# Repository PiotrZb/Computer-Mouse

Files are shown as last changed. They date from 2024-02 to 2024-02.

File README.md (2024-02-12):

# Computer Mouse project 🖱️

## Description 📜

Educational computer mouse project created in KiCad. The project includes an electrical schematic, PCB schematic and Gerber production files.

pcb1

pcb2

## Contributors 🤝

<div style="display: flex;">
    <a href="https://github.com/lukaszkusgithub"> 
       
    </a> 
</div>

## License 📄



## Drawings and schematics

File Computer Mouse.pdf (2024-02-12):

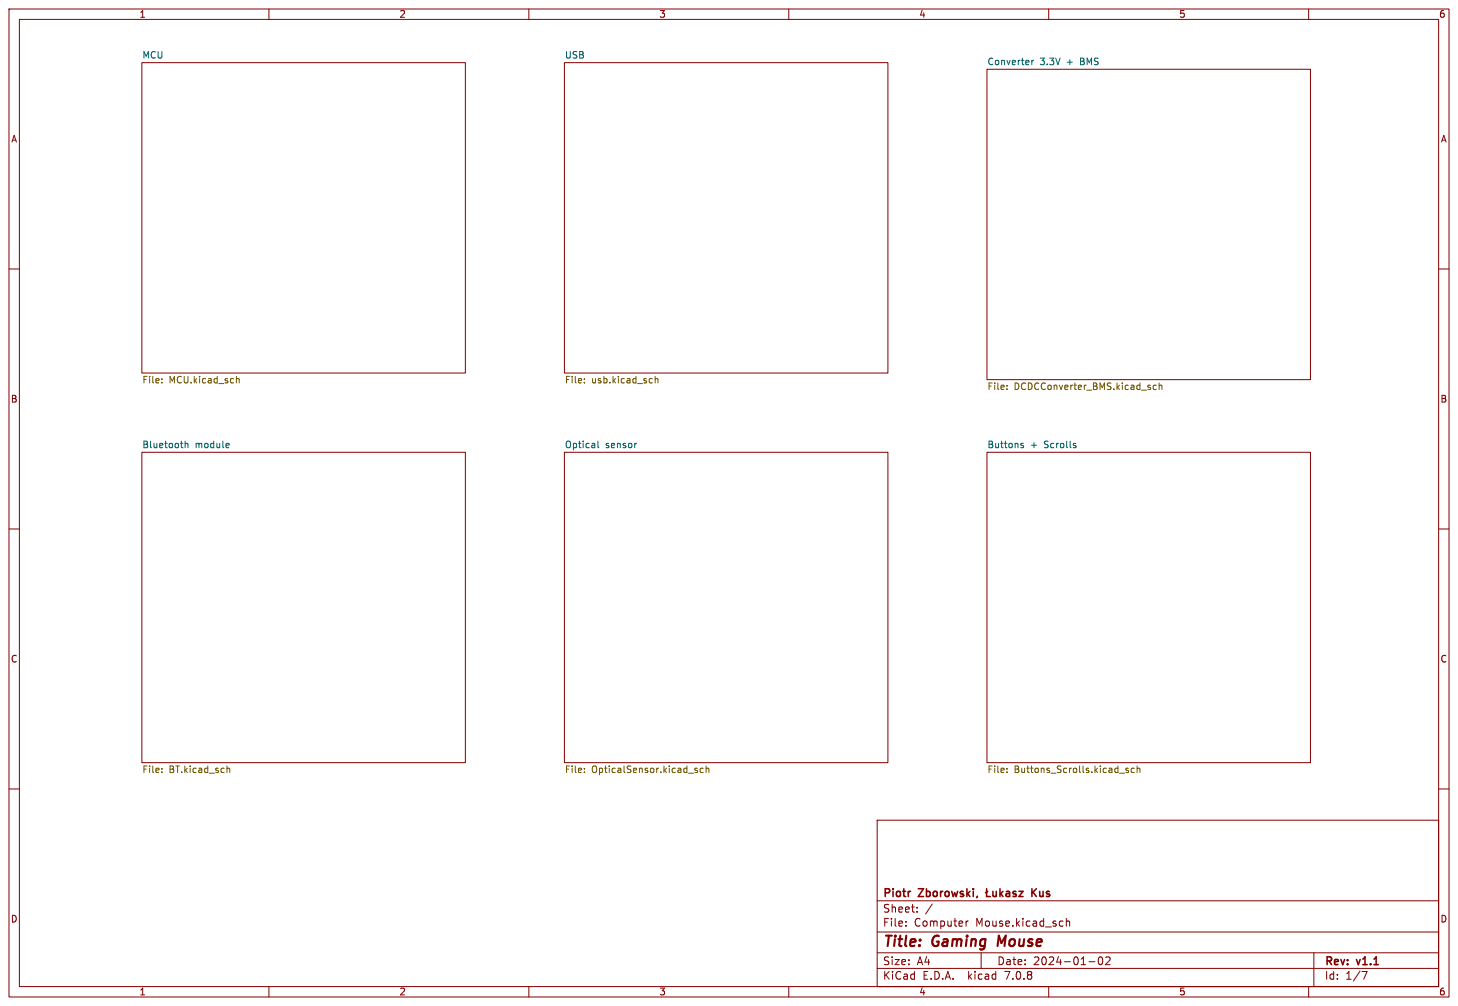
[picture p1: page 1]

File: DCDCConverter_BMS.kicad_sch Optical sensor File: OpticalSensor.kicad_sch

Id: 1/7 Title: Gaming Mouse

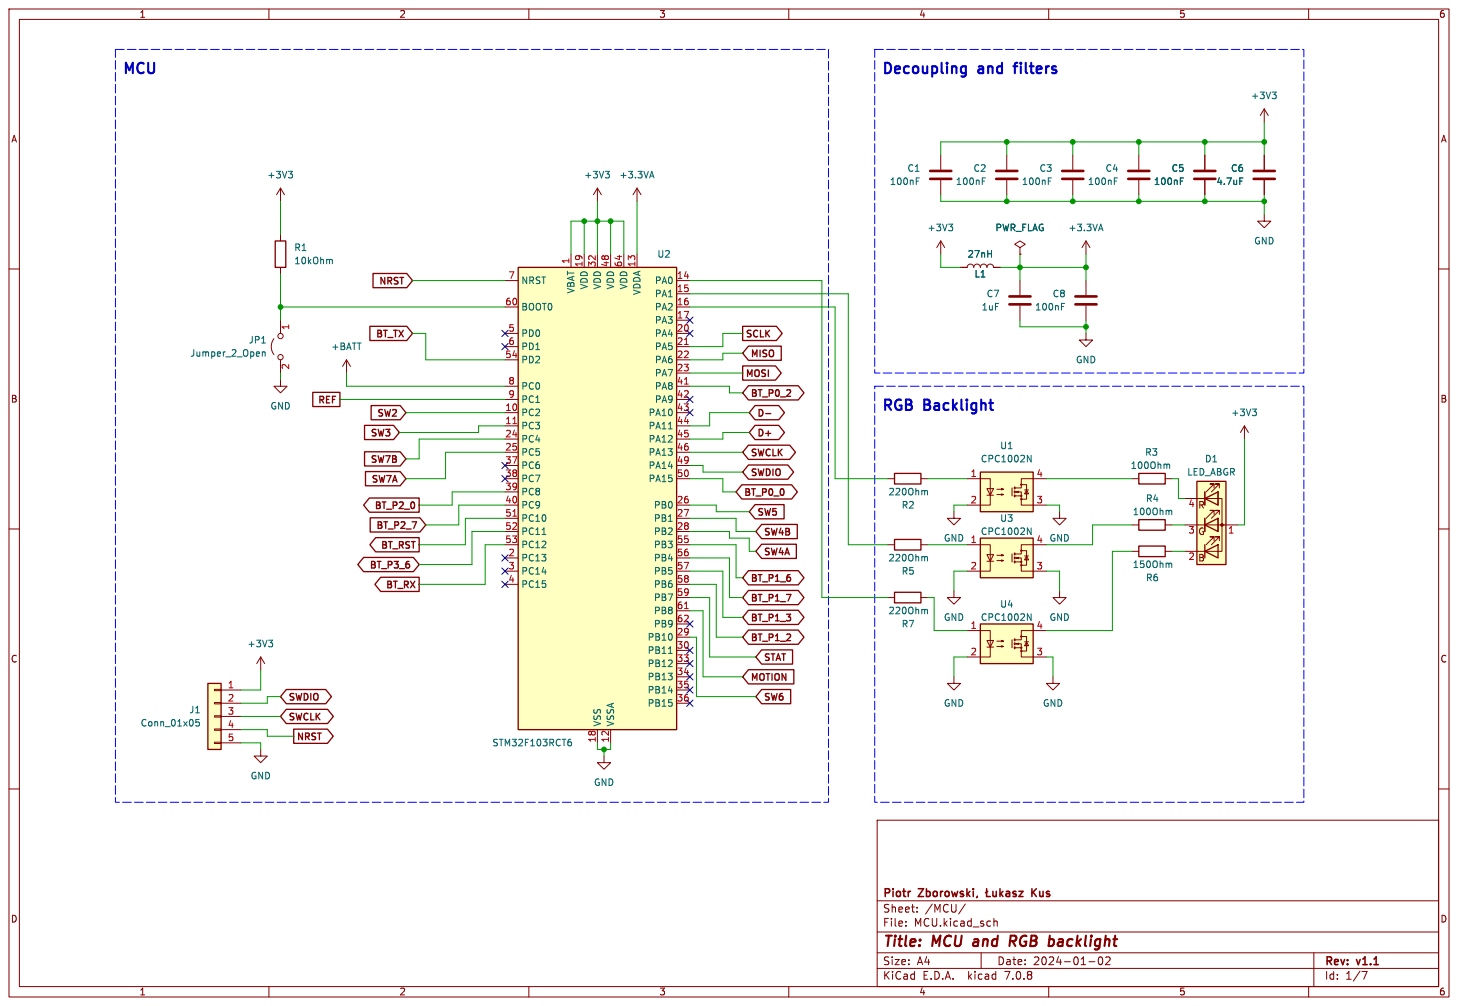
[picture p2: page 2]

1 PC2 10 PC3 11 VSSA 12 VDDA 13 PA0 14 PA1 15 PA2 16 PA3 17 VSS 18 VDD 19 PC13 2 PA4 20 PA5 21 PA6 22 PA7 23 PC4 24 PC5 25 PB0 26 PB1 27 PB2 28 PB10 29 PC14 3 PB11 30 VDD 32 PB12 33 PB13 34 PB14 35 PB15 36 PC6 37 PC7 38 PC8 39 PC15 4 PC9 40 PA8 41 PA9 42 PA10 43 PA11 44 PA12 45 PA13 46 VDD 48 PA14 49 PD0 5 PA15 50 PC10 51 PC11 52 PC12 53 PD2 54 PB3 55 PB4 56 PB5 57 PB6 58 PB7 59 PD1 6 BOOT0 60 PB8 61 PB9 62 VDD 64 NRST 7 PC0 8 PC1 9 U2 STM32F103RCT6

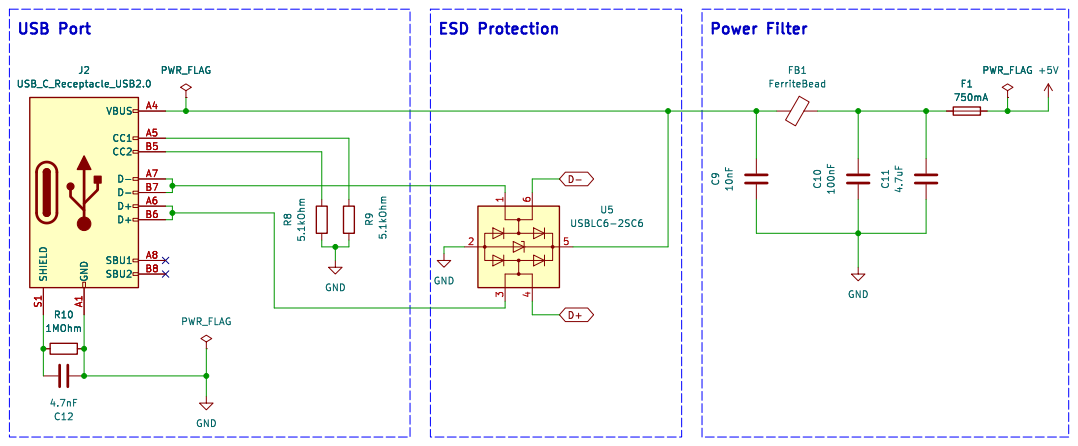
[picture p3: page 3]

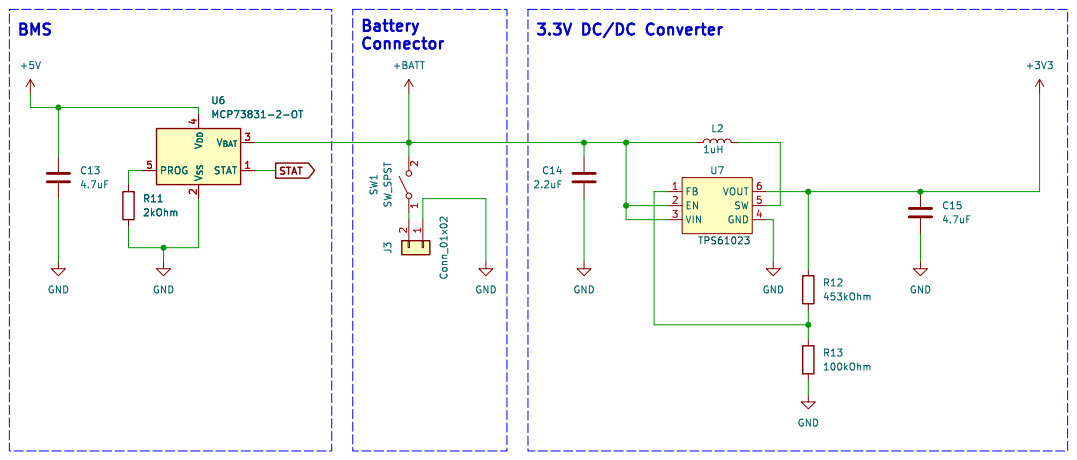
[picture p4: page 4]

1 2 SW1 SW_SPST STAT BMS Battery 3.3V DC/DC Converter

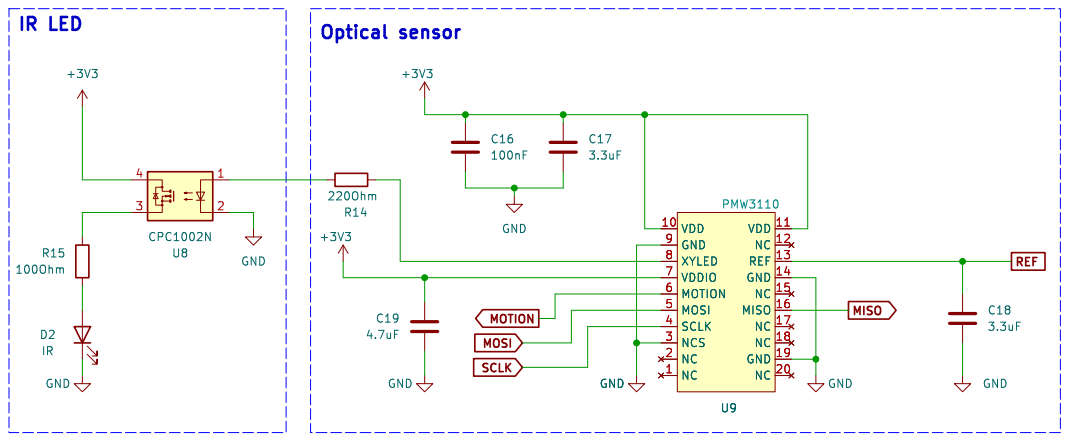
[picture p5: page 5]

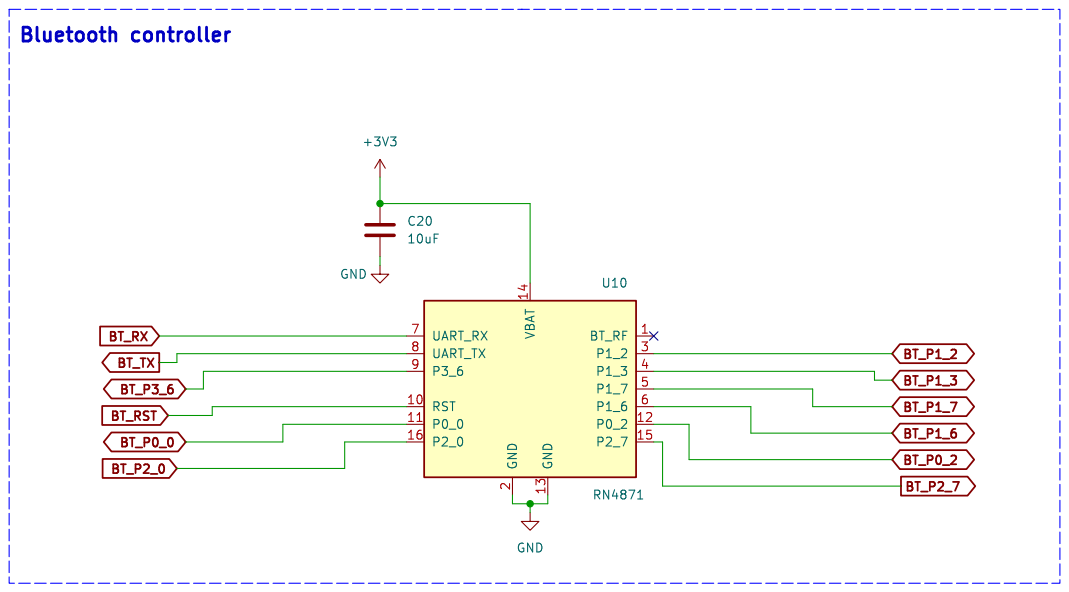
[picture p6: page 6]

Id: 5/7 Title: Bluetooth module

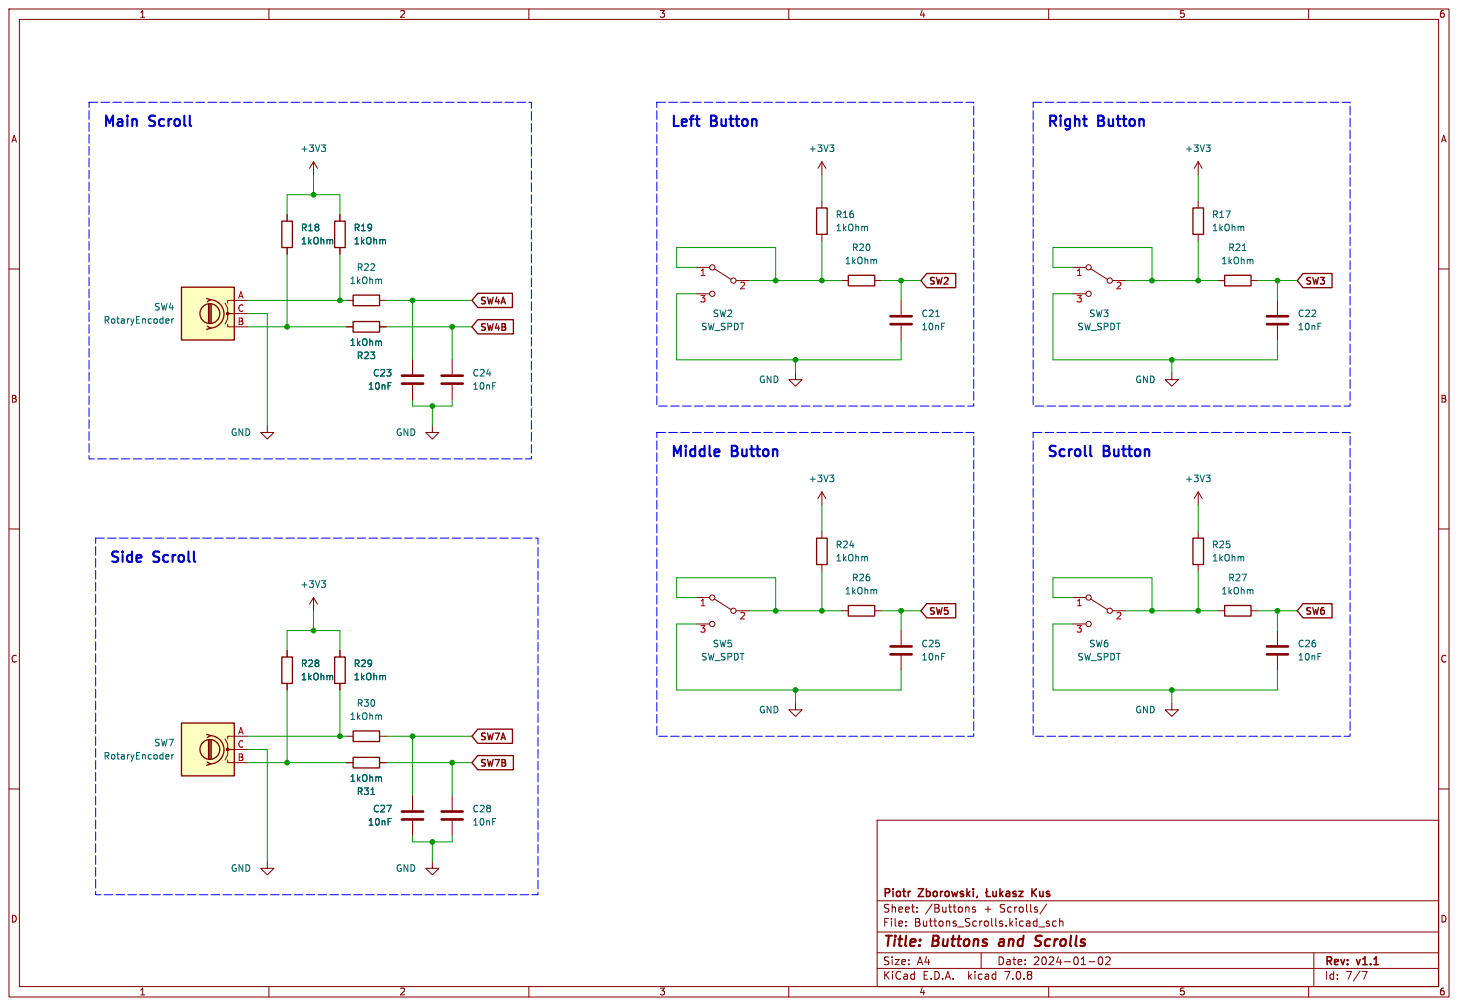
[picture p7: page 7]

Id: 7/7 Title: Buttons and Scrolls

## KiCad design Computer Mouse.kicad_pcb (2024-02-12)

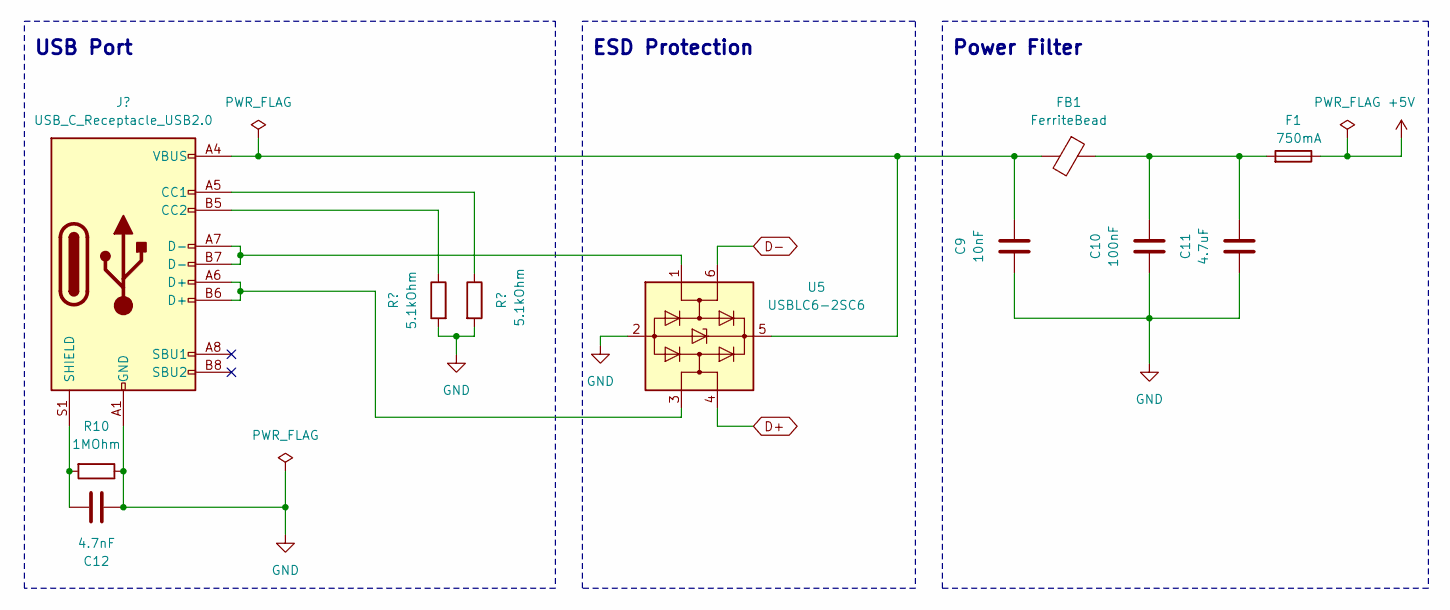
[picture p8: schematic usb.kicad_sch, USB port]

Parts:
C9: 10nF; C_0603_1608Metric
C10: 100nF; C_0805_2012Metric
C11: 4.7uF; C_0603_1608Metric
C12: 4.7nF; C_0805_2012Metric
F1: 750mA; Fuse_0402_1005Metric
FB1: FerriteBead; C_2220_5650Metric
J2: USB_C_Receptacle_USB2.0; USB_C_Receptacle_HRO_TYPE-C-31-M-12
R8, R9: 5.1kOhm; R_0603_1608Metric
R10: 1MOhm; R_1206_3216Metric
U5: USBLC6-2SC6; SOT-23-6

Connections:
+5V: F1.1; also elsewhere on the board
D+: U5.4 (I/O2); also elsewhere on the board
D-: U5.6 (I/O1); also elsewhere on the board
unnamed: C10.2, C11.2, F1.2, FB1.1
unnamed: J2.A5 (CC1), R9.1
unnamed: J2.B5 (CC2), R8.1
unnamed: J2.A6 (D+), J2.B6 (D+), U5.3 (I/O2)
unnamed: J2.A7 (D-), J2.B7 (D-), U5.1 (I/O1)
unnamed: C12.2, J2.S1 (SHIELD), R10.2
unnamed: C9.2, FB1.2, J2.A4 (VBUS), J2.A9 (VBUS), J2.B4 (VBUS), J2.B9 (VBUS), U5.5 (VBUS)

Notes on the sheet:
Power Filter
ESD Protection
USB Port

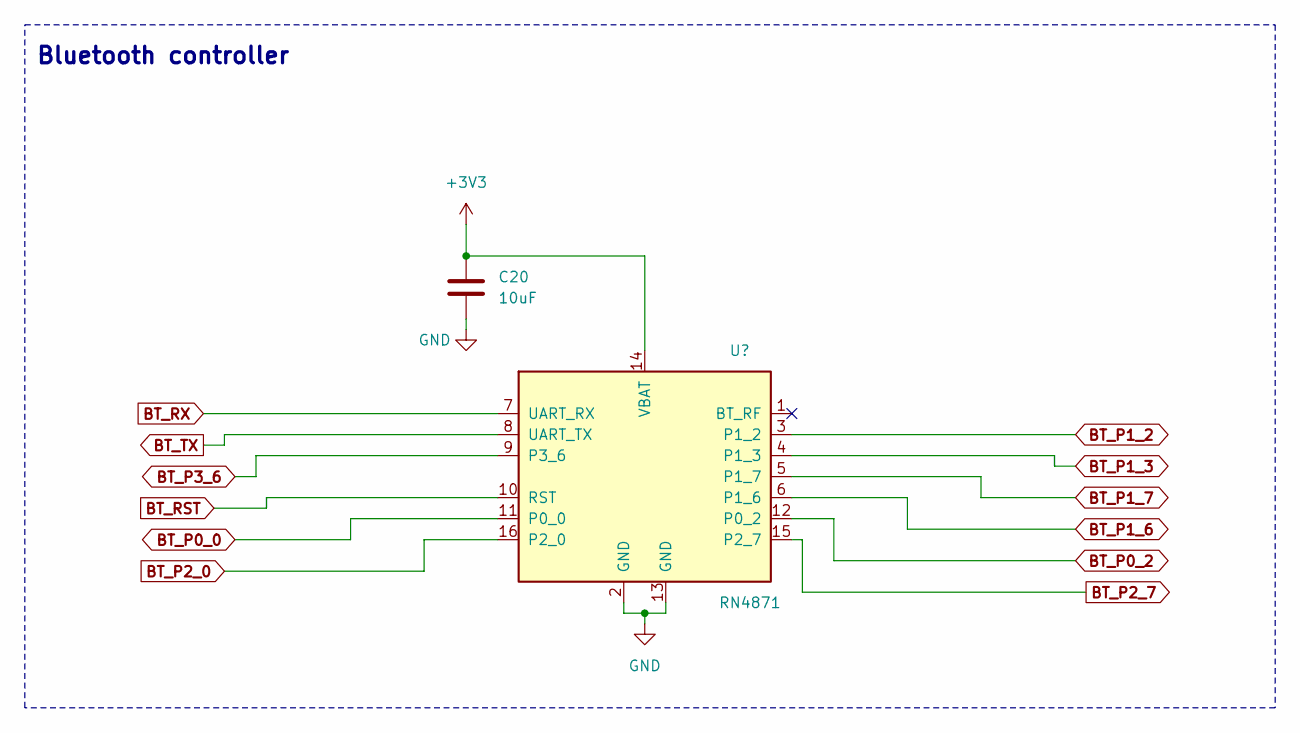
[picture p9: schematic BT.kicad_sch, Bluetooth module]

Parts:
C20: 10uF; C_1206_3216Metric
U10: RN4871; Microchip_RN4871

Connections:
BT_P0_0: U10.11 (P0_0); also elsewhere on the board
BT_P0_2: U10.12 (P0_2); also elsewhere on the board
BT_P1_2: U10.3 (P1_2); also elsewhere on the board
BT_P1_3: U10.4 (P1_3); also elsewhere on the board
BT_P1_6: U10.6 (P1_6); also elsewhere on the board
BT_P1_7: U10.5 (P1_7); also elsewhere on the board
BT_P2_0: U10.16 (P2_0); also elsewhere on the board
BT_P2_7: U10.15 (P2_7); also elsewhere on the board
BT_P3_6: U10.9 (P3_6); also elsewhere on the board
BT_RST: U10.10 (RST); also elsewhere on the board
BT_RX: U10.7 (UART_RX); also elsewhere on the board
BT_TX: U10.8 (UART_TX); also elsewhere on the board

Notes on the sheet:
Bluetooth controller

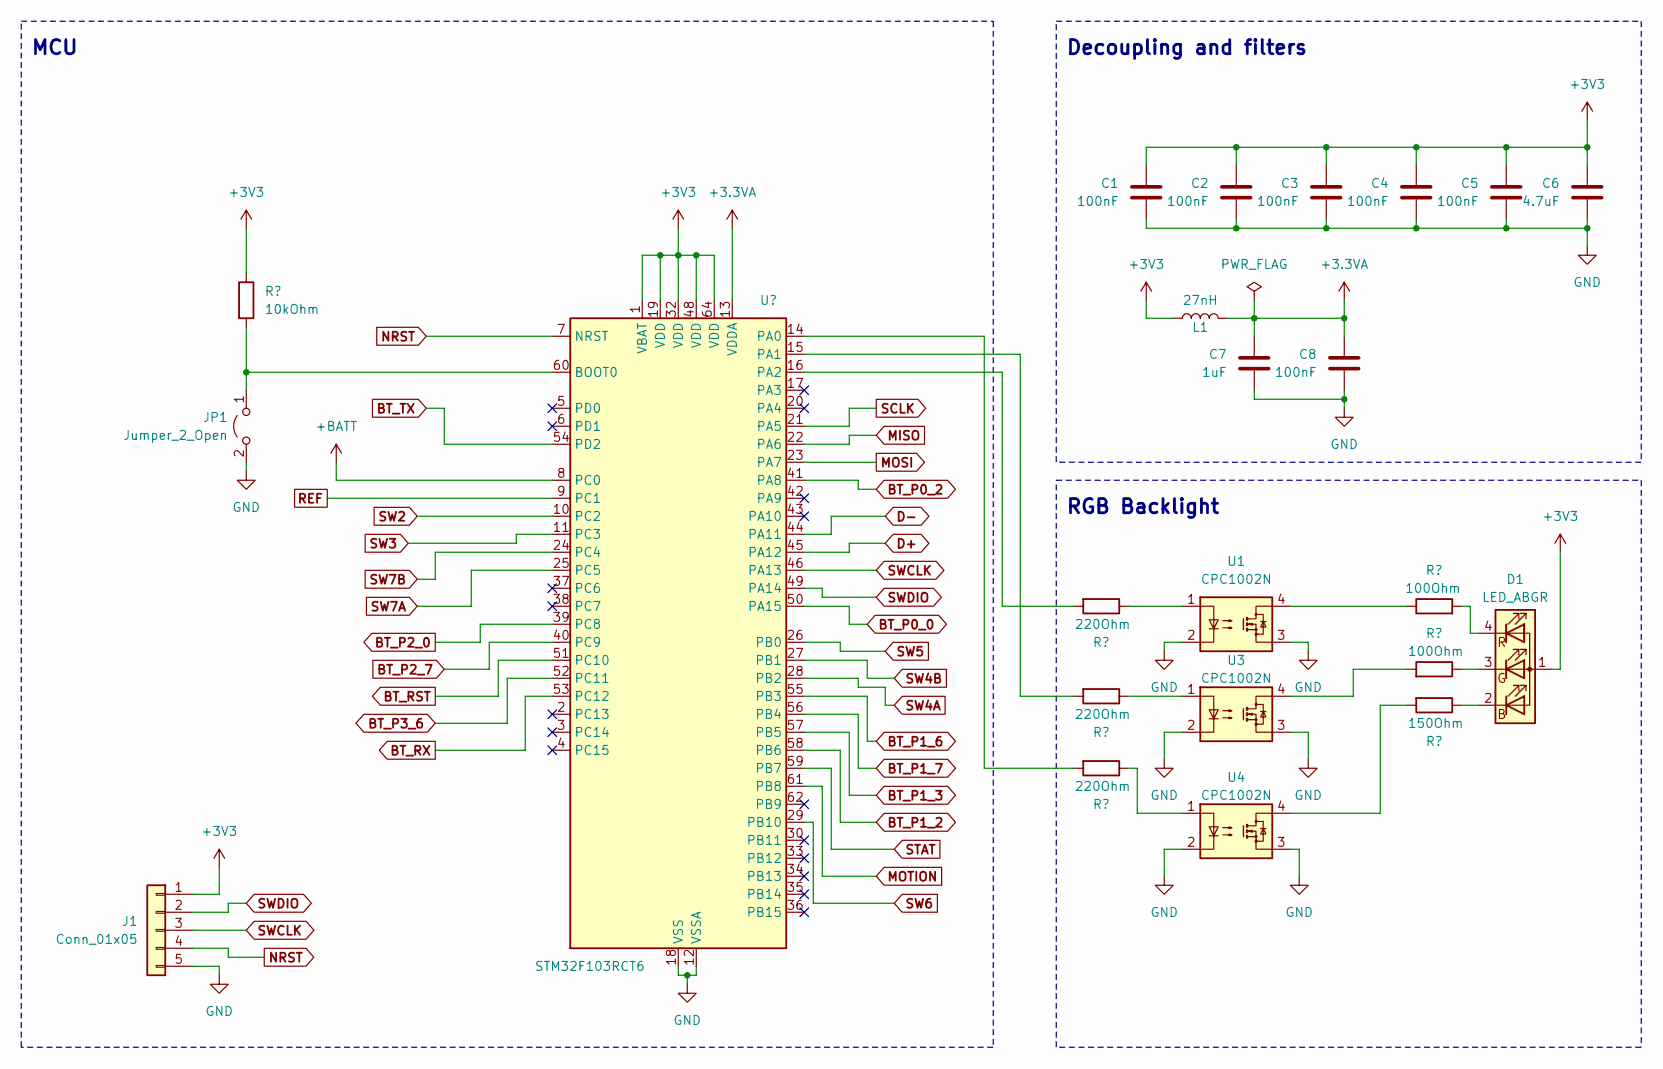
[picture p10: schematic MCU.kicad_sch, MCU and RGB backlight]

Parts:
C1, C2, C3, C4, C5, C8: 100nF; C_0805_2012Metric
C6: 4.7uF; C_0603_1608Metric
C7: 1uF; C_0603_1608Metric
D1: LED_ABGR; LED_D5.0mm-4_RGB_Wide_Pins
J1: Conn_01x05; JST_EH_B5B-EH-A_1x05_P2.50mm_Vertical
JP1: Jumper_2_Open; SolderJumper-2_P1.3mm_Bridged2Bar_Pad1.0x1.5mm
L1: 27nH; L_1210_3225Metric
R1: 10kOhm; R_0805_2012Metric
R2, R5, R7: 220Ohm; R_1206_3216Metric
R3, R4: 100Ohm; R_0805_2012Metric
R6: 150Ohm; R_1206_3216Metric
U1, U3, U4: CPC1002N; SOP-4_3.8x4.1mm_P2.54mm
U2: STM32F103RCT6; LQFP-64_10x10mm_P0.5mm

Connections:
+3.3VA: C7.1, C8.1, L1.1, U2.13 (VDDA)
+BATT: U2.8 (PC0); also elsewhere on the board
BT_P0_0: U2.50 (PA15); also elsewhere on the board
BT_P0_2: U2.41 (PA8); also elsewhere on the board
BT_P1_2: U2.58 (PB6); also elsewhere on the board
BT_P1_3: U2.57 (PB5); also elsewhere on the board
BT_P1_6: U2.55 (PB3); also elsewhere on the board
BT_P1_7: U2.56 (PB4); also elsewhere on the board
BT_P2_0: U2.39 (PC8); also elsewhere on the board
BT_P2_7: U2.40 (PC9); also elsewhere on the board
BT_P3_6: U2.52 (PC11); also elsewhere on the board
BT_RST: U2.51 (PC10); also elsewhere on the board
BT_RX: U2.53 (PC12); also elsewhere on the board
BT_TX: U2.54 (PD2); also elsewhere on the board
D+: U2.45 (PA12); also elsewhere on the board
D-: U2.44 (PA11); also elsewhere on the board
MISO: U2.22 (PA6); also elsewhere on the board
MOSI: U2.23 (PA7); also elsewhere on the board
MOTION: U2.61 (PB8); also elsewhere on the board
NRST: J1.4, U2.7 (NRST)
unnamed: D1.2 (BK), R6.1
unnamed: D1.3 (GK), R4.1
unnamed: D1.4 (RK), R3.2
unnamed: JP1.1 (A), R1.2, U2.60 (BOOT0)
unnamed: R3.1, U1.4
unnamed: R4.2, U3.4
unnamed: R5.1, U3.1
unnamed: R6.2, U4.4
unnamed: R7.1, U4.1
unnamed: R7.2, U2.14 (PA0)
unnamed: R5.2, U2.15 (PA1)
REF: U2.9 (PC1); also elsewhere on the board
STAT: U2.59 (PB7); also elsewhere on the board
SW2: U2.10 (PC2); also elsewhere on the board
SW3: U2.11 (PC3); also elsewhere on the board
SW4A: U2.28 (PB2); also elsewhere on the board
SW4B: U2.27 (PB1); also elsewhere on the board
SW5: U2.26 (PB0); also elsewhere on the board
SW6: U2.29 (PB10); also elsewhere on the board
SW7A: U2.25 (PC5); also elsewhere on the board
SW7B: U2.24 (PC4); also elsewhere on the board
SWCLK: J1.3, U2.46 (PA13)
SWDIO: J1.2, U2.49 (PA14)

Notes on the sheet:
Decoupling and filters
RGB Backlight
MCU

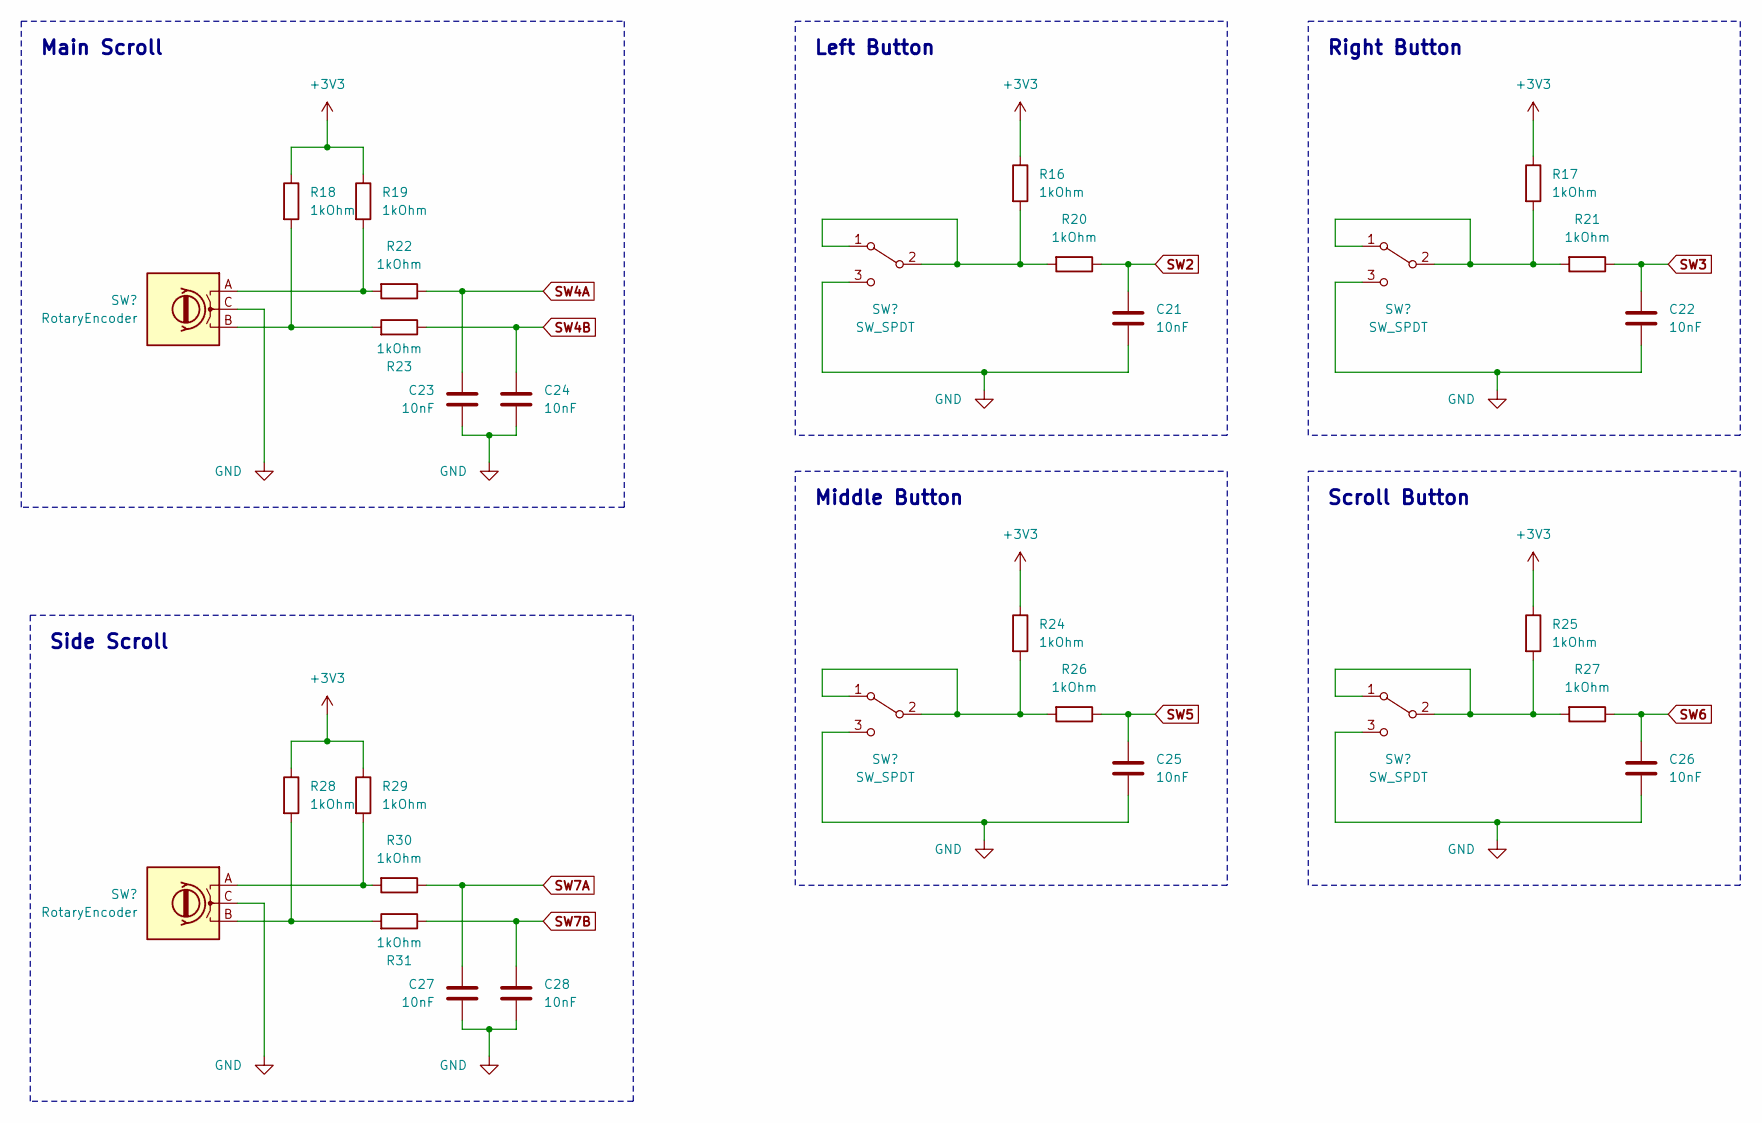
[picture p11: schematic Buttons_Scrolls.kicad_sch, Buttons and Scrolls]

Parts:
C21, C22, C23, C24, C25, C26, C27, C28: 10nF; C_0603_1608Metric
R16, R17, R18, R19, R20, R21, R22, R23, R24, R25, R26, R27, R28, R29, R30, R31: 1kOhm; R_0603_1608Metric
SW2, SW3, SW5, SW6: SW_SPDT; Mouse_Switch
SW4, SW7: RotaryEncoder; TTC_rotary_encoder

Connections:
unnamed: R18.2, R23.2, SW4.B
unnamed: R19.2, R22.2, SW4.A
unnamed: R28.2, R31.2, SW7.B
unnamed: R29.2, R30.2, SW7.A
unnamed: R16.2, R20.2, SW2.1 (A), SW2.2 (B)
unnamed: R17.2, R21.2, SW3.1 (A), SW3.2 (B)
unnamed: R24.2, R26.2, SW5.1 (A), SW5.2 (B)
unnamed: R25.2, R27.2, SW6.1 (A), SW6.2 (B)
SW2: C21.1, R20.1; also elsewhere on the board
SW3: C22.1, R21.1; also elsewhere on the board
SW4A: C23.1, R22.1; also elsewhere on the board
SW4B: C24.1, R23.1; also elsewhere on the board
SW5: C25.1, R26.1; also elsewhere on the board
SW6: C26.1, R27.1; also elsewhere on the board
SW7A: C27.1, R30.1; also elsewhere on the board
SW7B: C28.1, R31.1; also elsewhere on the board

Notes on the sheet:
Middle Button
Scroll Button
Left Button
Side Scroll
Right Button
Main Scroll

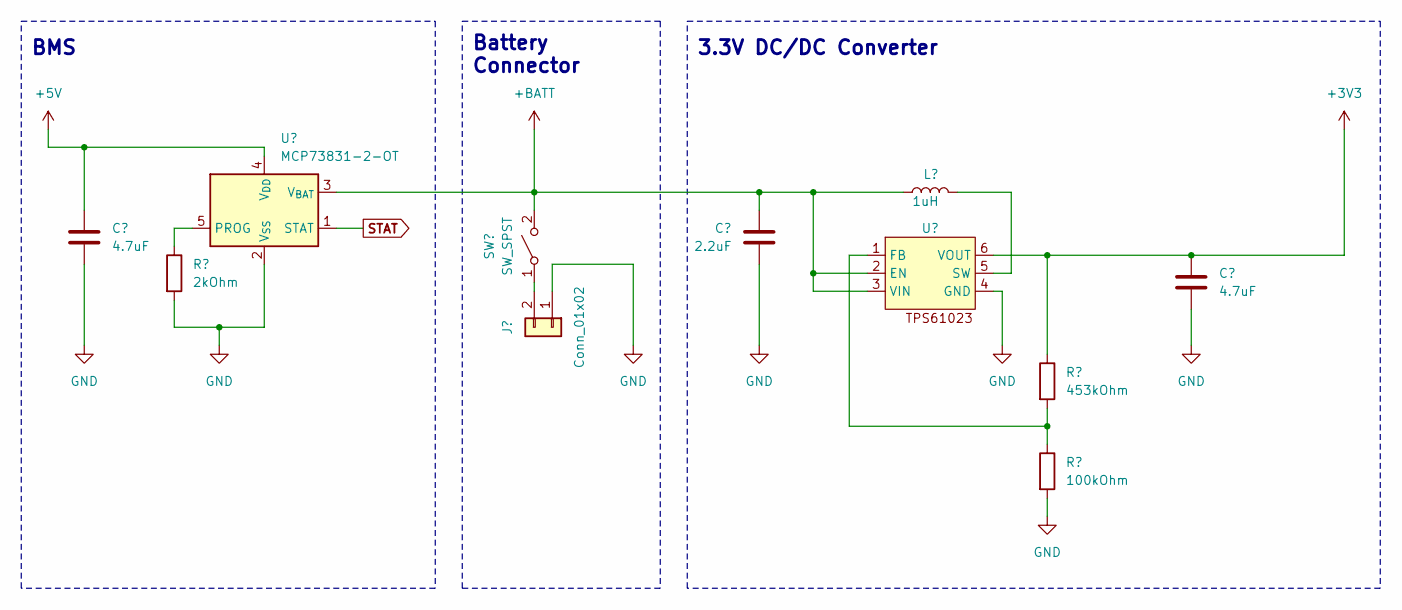
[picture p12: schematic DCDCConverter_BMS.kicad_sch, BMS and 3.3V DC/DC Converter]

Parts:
C13, C15: 4.7uF; C_0603_1608Metric
C14: 2.2uF; C_0805_2012Metric
J3: Conn_01x02; JST_EH_B2B-EH-A_1x02_P2.50mm_Vertical
L2: 1uH; L_0603_1608Metric_Pad1.05x0.95mm_HandSolder
R11: 2kOhm; R_0805_2012Metric
R12: 453kOhm; R_0805_2012Metric
R13: 100kOhm; R_0805_2012Metric
SW1: SW_SPST; SW_DIP_SPSTx01_Slide_6.7x4.1mm_W7.62mm_P2.54mm_LowProfile
U6: MCP73831-2-OT; SOT-23-5
U7: TPS61023_DC_DC

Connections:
+5V: C13.1, U6.4 (V_{DD}); also elsewhere on the board
+BATT: C14.1, L2.1, SW1.2 (B), U6.3 (V_{BAT}), U7.2 (EN), U7.3 (VIN); also elsewhere on the board
unnamed: J3.2, SW1.1 (A)
unnamed: R11.1, U6.5 (PROG)
unnamed: R12.2, R13.1, U7.1 (FB)
unnamed: L2.2, U7.5 (SW)
STAT: U6.1 (STAT); also elsewhere on the board

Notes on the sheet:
BMS
Battery Connector
3.3V DC/DC Converter

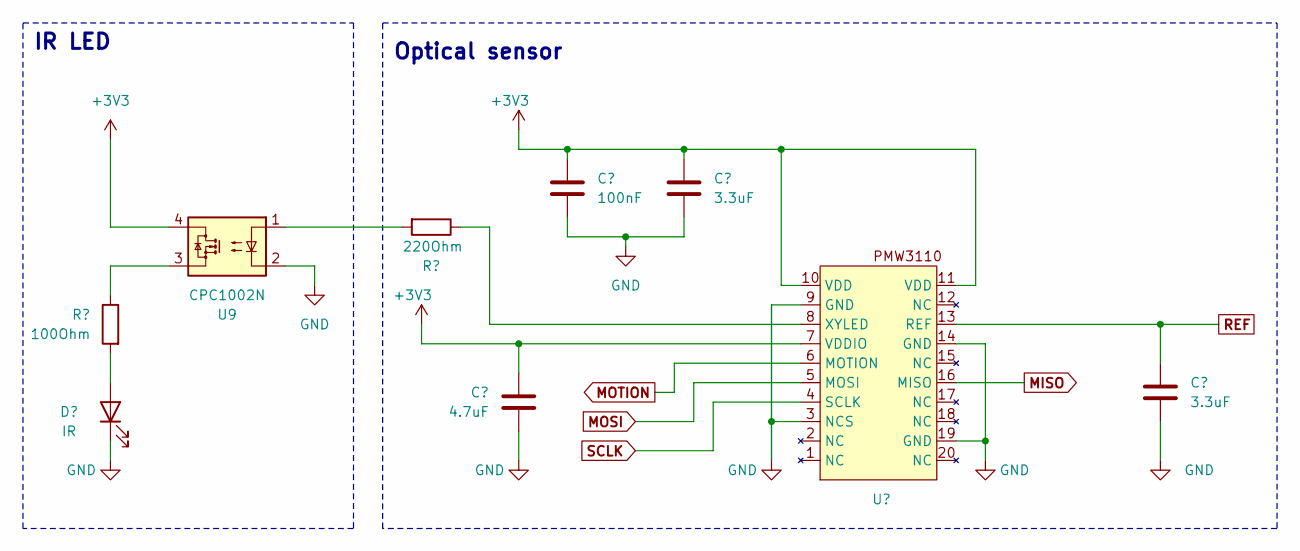
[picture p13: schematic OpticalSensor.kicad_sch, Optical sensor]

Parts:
C16: 100nF; C_0805_2012Metric
C17, C18: 3.3uF; C_0805_2012Metric
C19: 4.7uF; C_0603_1608Metric
D2: IR; LED_D5.0mm_Horizontal_O1.27mm_Z3.0mm_Clear
R2: 220Ohm; R_1206_3216Metric
R15: 100Ohm; R_0805_2012Metric
U9: CPC1002N; SOP-4_3.8x4.1mm_P2.54mm

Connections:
MISO: U9.16 (MISO); also elsewhere on the board
MOSI: U9.5 (MOSI); also elsewhere on the board
MOTION: U9.6 (MOTION); also elsewhere on the board
unnamed: D2.2 (A), R15.2
REF: C18.1, U9.13 (REF); also elsewhere on the board

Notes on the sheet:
IR LED
Optical sensor

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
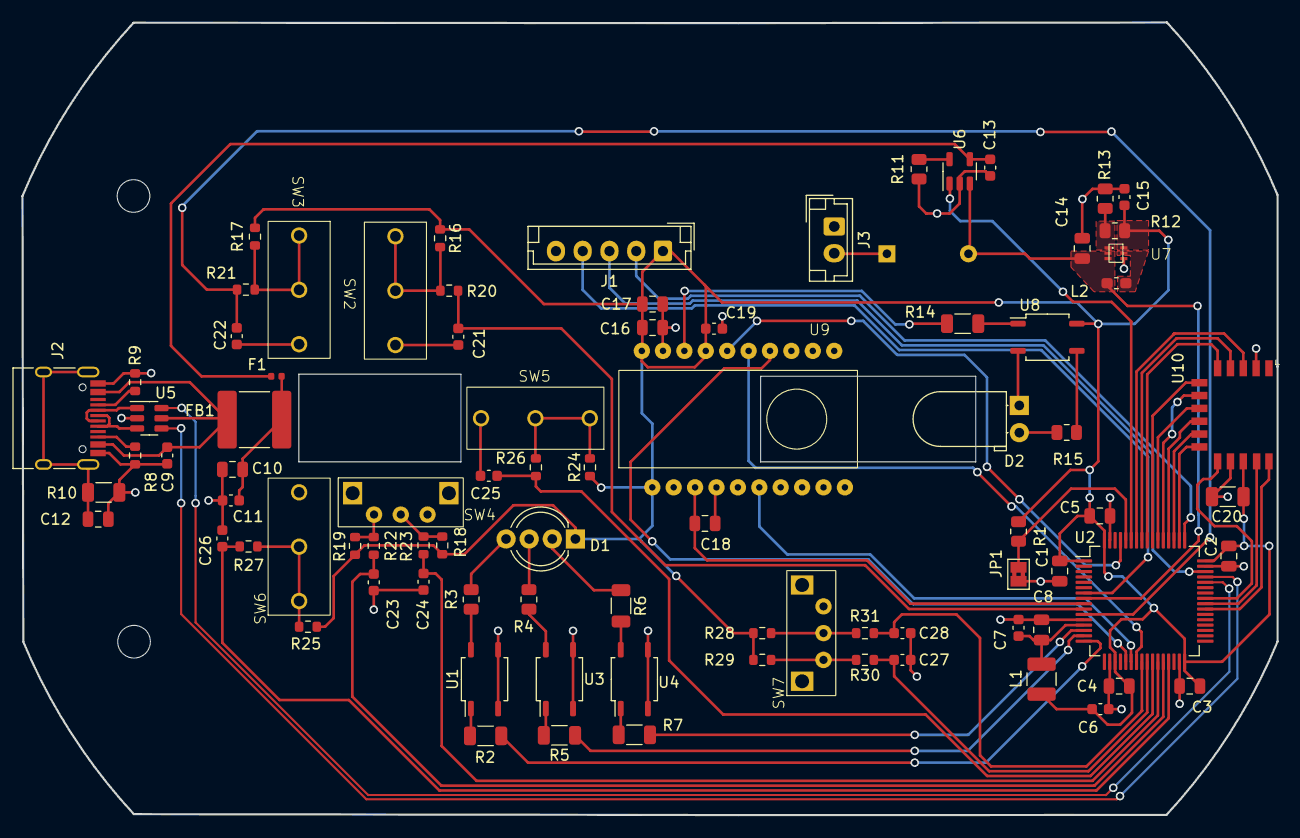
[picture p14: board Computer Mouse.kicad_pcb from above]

Board: 2 copper layers, 117.3 x 74.1 mm, 86 parts (1 on the bottom side), 72 nets.

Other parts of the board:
R14: 220Ohm; R_1206_3216Metric
U8: CPC1002N; SOP-4_3.8x4.1mm_P2.54mm

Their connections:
unnamed: R14.2, U8.1

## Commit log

2023-11-12 BT module
    [Computer Mouse.kicad_sch]
2023-11-12 ERC fix
    [Computer Mouse.kicad_sch]
2023-11-14 New footprints
    [Computer Mouse.kicad_sch]
2023-11-19 New layout, pull-up resistors, filters, decoupling capacitors
    [BT.kicad_sch, Buttons_Scrolls.kicad_sch, Computer Mouse.kicad_sch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]
2023-12-10 Arrangement of elements
    [Computer Mouse.kicad_pcb]
2023-12-10 Board outlines
    [Computer Mouse.kicad_pcb]
2023-12-10 MCU-BT connection
    [Computer Mouse.kicad_pcb, MCU.kicad_sch]
2023-12-10 Other connections
    [Computer Mouse.kicad_pcb, MCU.kicad_sch]
2024-01-02 3.3V paths, new usb module
    [Computer Mouse.kicad_pcb, usb.kicad_sch]
2024-01-02 GND fields
    [BT.kicad_sch, Buttons_Scrolls.kicad_sch, Computer Mouse.kicad_pcb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]
2024-02-12 Readme update, gerber files
    [Computer Mouse-B_Cu.gbr, Computer Mouse-B_Mask.gbr, Computer Mouse-B_Paste.gbr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]

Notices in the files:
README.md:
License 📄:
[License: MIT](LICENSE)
